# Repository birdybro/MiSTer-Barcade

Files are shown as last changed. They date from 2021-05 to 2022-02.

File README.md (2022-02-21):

# MiSTer-Barcade (WORK IN PROGRESS)

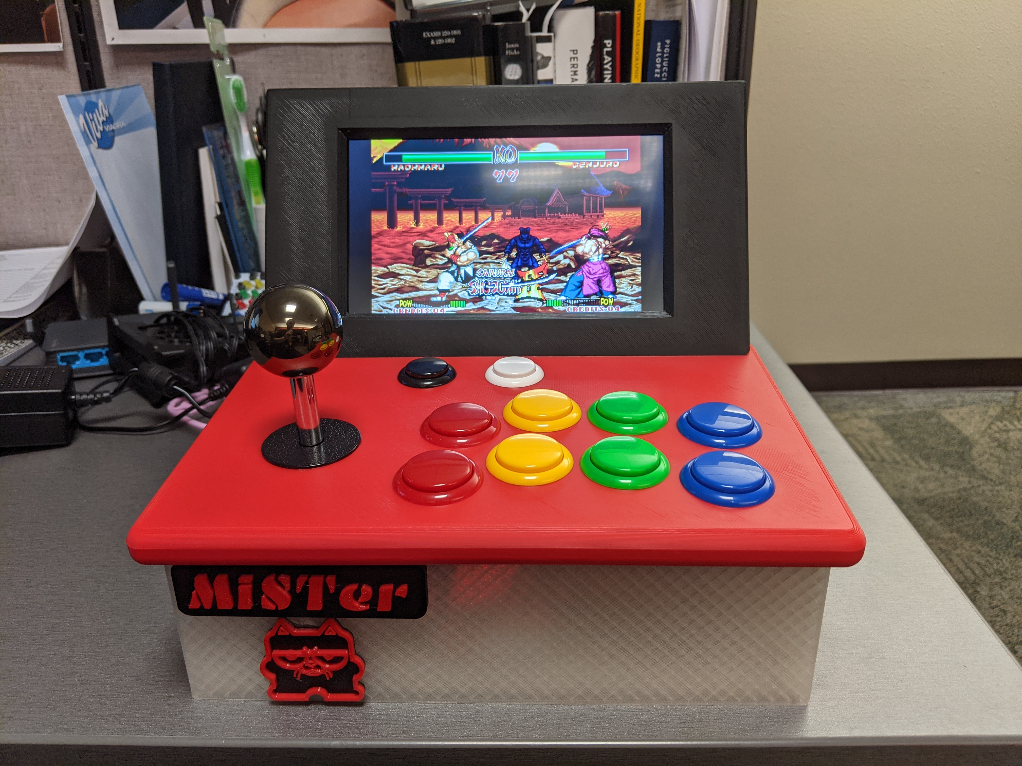
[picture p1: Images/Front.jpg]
Front of MiSTer Barcade


License: Creative Common Attributions License (and all thingiverse files were the same)

## Description

This is a project to build a Mini Bartop Arcade system with a MiSTer FPGA device integrated into it. It's not meant to be the best, it's just meant to be printable on cheap enthusiast 3d printers, using decently high quality components. This is not a very cheap project, if you want to make it cheaper, substitute a raspberry pi like the above-linked original source of the print from Thingiverse by iClint, and substitue the screen for a cheaper one from Aliexpress. All costs below are based on my personal selection of items as of May 2021. Your results and methods may vary.

## Tools Required
* [Metric Hex Wrench set](https://www.amazon.com/TEKTON-Wrench-Metric-13-Piece-25272/dp/B00I5THFR4/)
* [Loctite Ultra Gel Control Super Glue](https://www.amazon.com/dp/B01EZTPXEO) (or another cyanoacrylate super glue for bonding PLA pieces of different colors together)
* [Power drill](https://www.amazon.com/Dewalt-DCD771C2-Cordless-Lithium-Ion-Compact/dp/B00ET5VMTU/)
* [M3 Tap bits](https://www.amazon.com/Hakkin-Nitriding-Plastic-Tapping-Cutting/dp/B07S5KKCS4)

## Bill of Materials

### MiSTer FPGA Platform devices
* [Terasic DE10-Nano](https://www.digikey.com/en/products/detail/terasic-inc/P0496/6817231) - $170.00
* [Mean Well 5v 20W 4A Power Supply](https://www.digikey.com/en/products/detail/mean-well-usa-inc/GST25A05-P1J/7703645) - $16.63
* [Mean Well NEMA5-15P to IEC320 Power Cored](https://www.digikey.com/en/products/detail/mean-well-usa-inc/YP12-YC12/7707223) - $ 5.78
* [128MB MiSTer FPGA SDRAM Add-on Board](https://misteraddons.com/products/sdram-xsd-2-5-128mb) - $60.00
* [USB Hub Add-on board With DC Splitter and USB Bracket](https://misteraddons.com/products/usb-hub-v2-1) - $50.00
* [Heatsink](https://www.amazon.com/gp/product/B01JB8MQ76/) - $9.97
* [2 pin 5v 40mm Fan](https://www.amazon.com/GeeekPi-Raspberry-40x40x10mm-Brushless-Radiator/dp/B07X6CXQLN) - $7.99

### Sanwa Joystick and Buttons
* [Sanwa JLF-TP-8YT Joystick](https://focusattack.com/sanwa-jlf-tp-8yt-joystick/) - Add 5-Pin Double End Female Harness, GT-Y Octo Gate, and KOWAL Flat Plate Converter - $35.20
* [10x Japanese Style .110" Harness](https://focusattack.com/spare-japanese-style-110-harness-for-zero-delay-usb-encoder-pcb/) - $4.50
* [8x Sanwa OBSF 30MM Pushbuttons](https://focusattack.com/buttons/sanwa/30mm/obsf-30-pushbutton/) - $19.60
* [2x Sanwa OBSF 24MM Pushbuttons](https://focusattack.com/buttons/sanwa/24mm/obsf-24-pushbutton/) - $4.50
* [Daemonbite KTRL Arcade Mini controller encoder](https://www.daemonbite.com/product/ktrl-arcade-mini/) - $23.18

### Adafruit Components
* [HDMI 7" 800x480 Display Backpack - Without Touch](https://www.adafruit.com/product/2406) - $79.95
* [Stereo 3.7W Class D Audio Amplifier - MAX98306](https://www.adafruit.com/product/987) - $8.95
* [Speaker - 3" Diameter - 4 Ohm 3 Watt](https://www.adafruit.com/product/1314) - $1.95

### Screws/mounts and other hardware
* [8x (100 in pack) M3 Hex Nuts](https://www.amazon.com/gp/product/B01IWUSDYY/) - $5.22
* [30x (50 in pack) M3x12mm Countersunk Hex Bolt](https://www.amazon.com/gp/product/B01E6EIC2S/) - $6.99
* [12x (80 in pack) M3x4mm Machine Screws](https://www.amazon.com/gp/product/B07WCT6VY6/) - $6.99

### Estimated total cost
$

## 3D Printing

All 3d Printed Parts were sliced in PrusaSlicer on a Prusa i3 MK3S+ set to 0.30mm draft profile (15% grid infill) using Hatchbox PLA, unless otherwise stated below.

### Arcade Cabinet

* [Front Panel](https://cdn.thingiverse.com/assets/3f/01/7c/28/23/Front_Panel.stl)
* [Top Panel](https://cdn.thingiverse.com/assets/83/88/73/ff/92/Top_panel.stl)
* [Left Panel](https://cdn.thingiverse.com/assets/d0/cb/0b/19/be/left_Panel.stl)
* [Right Panel](https://cdn.thingiverse.com/assets/4f/1d/11/f3/97/right_panel.stl)
* [Back Panel](https://cdn.thingiverse.com/assets/98/93/cd/c9/cd/Back_Panel.stl) - Print with generated supports, 0.2 detachable. The handle area will slouch otherwise. You may have to paint on support blockers to keep unnecessary supports from being made around the edges which would cause it to exceed the build plate size.
* [Base Panel](https://cdn.thingiverse.com/assets/87/da/83/f2/4b/Base_panel.stl)
* [Rubber Feet](https://cdn.thingiverse.com/assets/22/47/79/eb/ac/Rubber_foot.stl) - Use TPU instead of PLA because "rubber".
* [Control Panel 10 Buttons Remix by alecreator](https://cdn.thingiverse.com/assets/d9/a1/a0/62/c1/Mini_Arcade_10_buttons.stl) - Used 0.20mm Quality profile instead because it is an obvious cosmetic surface. Use supports or else some loose bridging occurs on the interior wall that connects to the Bezel. You may have to use paint-on support blockers around the edges except for the bezel-facing interior wall in order for the slicer to fit it to your build plate.
* [Bezel for Adafruit 7" screen](https://cdn.thingiverse.com/assets/7f/f2/e9/ba/73/Bezel-Adafruit_7_Touchscreen.stl)

### Decorations

## Notes
* Power stereo amp from GPIO on the DE10-nano. 5v is required. Occupy pin 11 (5v) and 12 (GND) of the available header.
* Power the fan from GPIO on the DE10-nano. 3.3v is required. Occupy pin 29 (3.3v) and 30 (GND) of the available header.
* The video mode that needs to be placed into the MiSTer.ini file for the Adafruit 7" 800x480 non-touch display is `video_mode=800,70,48,10,480,13,3,29,34483`

## Credits

Original source of print here --> [Mini Arcade Machine by iClint](https://www.thingiverse.com/thing:2216740)

Remixed content from here --> [Bezel File from Mini Arcade Machine by Franks3dShop](https://www.thingiverse.com/thing:3529914) and here --> [10 button control panel for Mini Arcade Machine by alecreator](https://www.thingiverse.com/thing:3817837)

Pacman files from here --> [Glowing Pac Man & Phantom by FablabMoebius](https://www.thingiverse.com/thing:303447)

Electrical Hazard sign from here --> [Hazard Signs Cut Remix](https://www.thingiverse.com/thing:4870304)

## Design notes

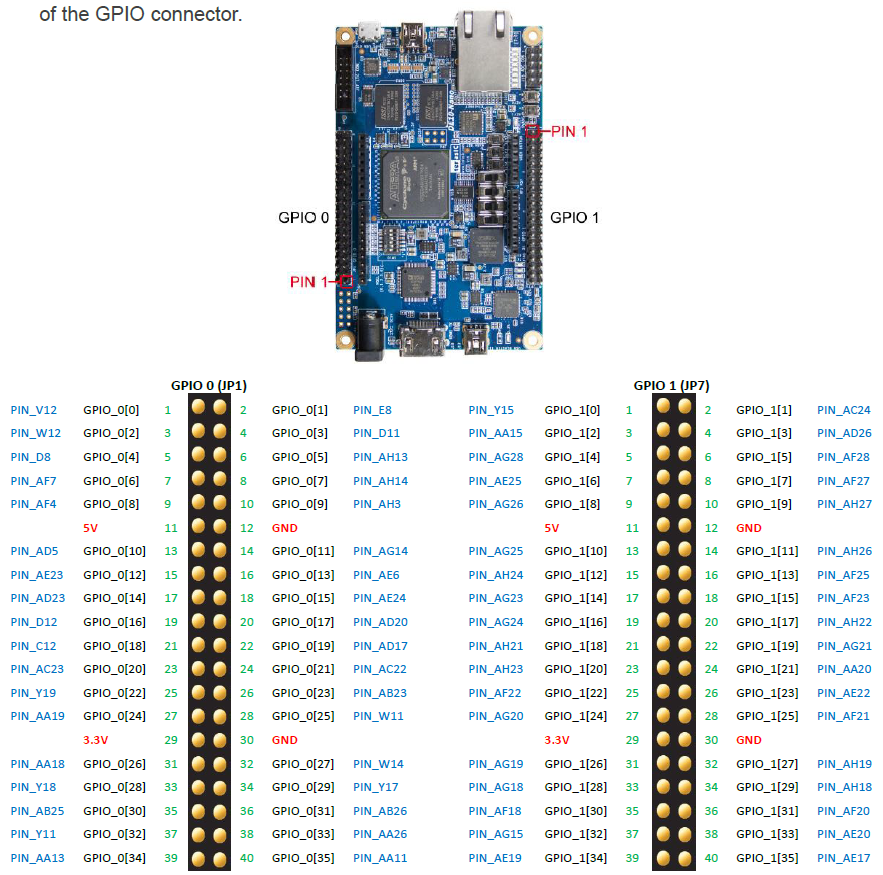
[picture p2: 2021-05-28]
Images/de10-nano_headers.png

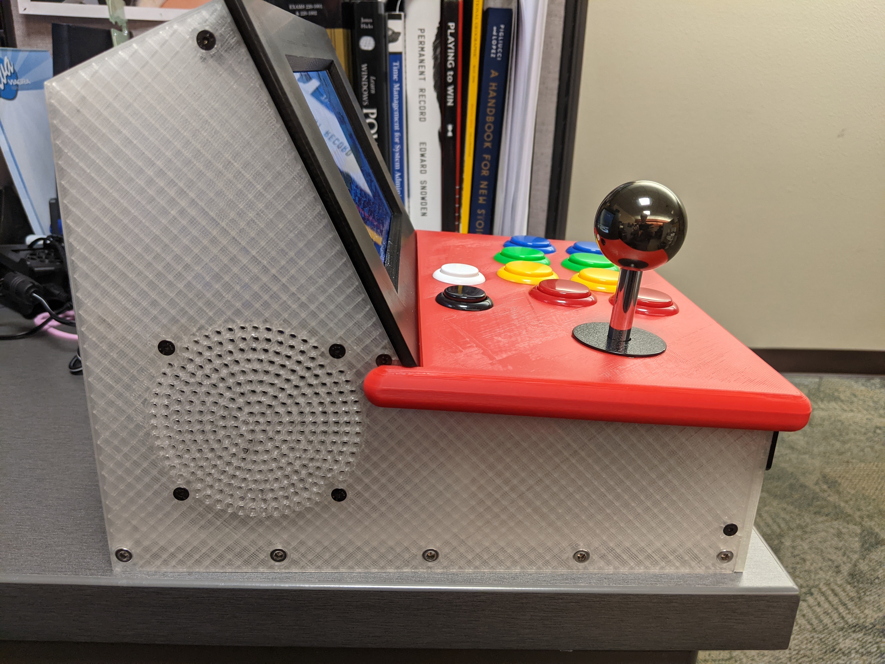
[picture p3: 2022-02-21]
Images/Side.jpg

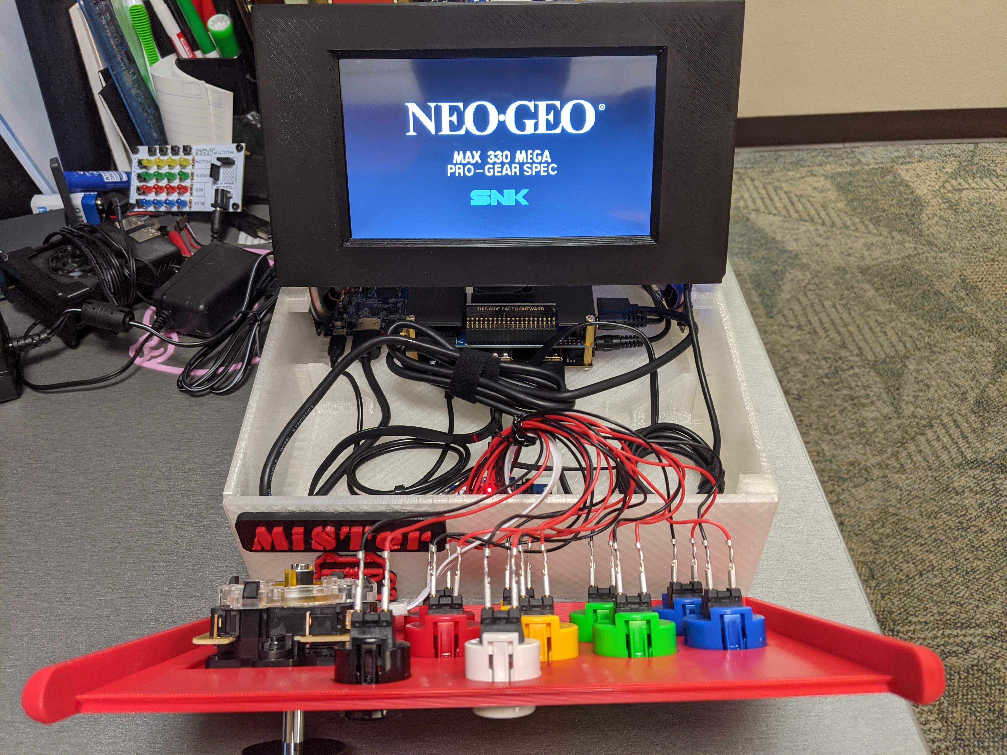
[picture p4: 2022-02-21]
Images/Inside.jpg

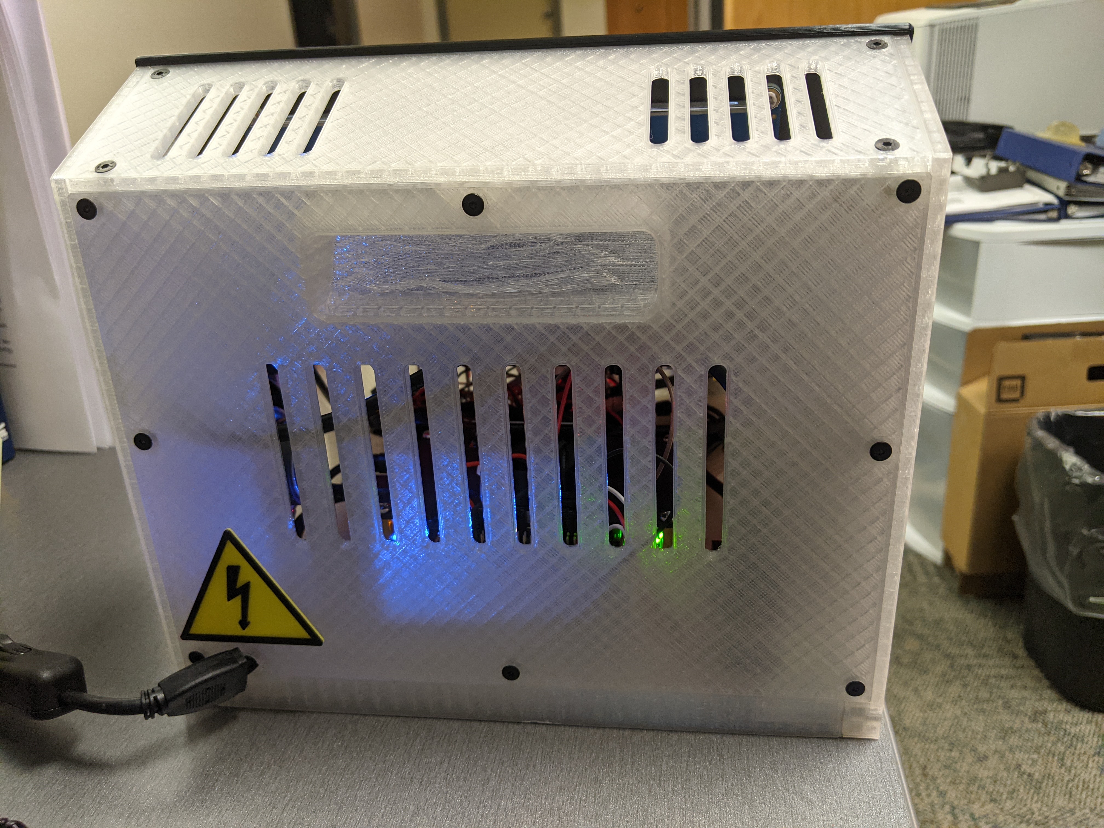
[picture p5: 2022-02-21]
Images/Rear.jpg

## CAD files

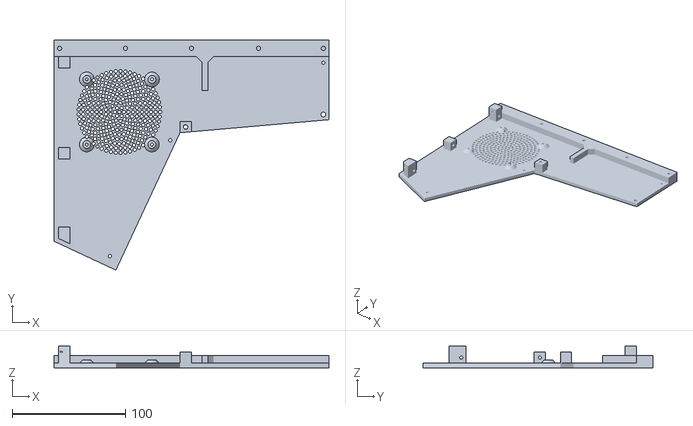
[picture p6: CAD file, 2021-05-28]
3d Printed Parts/Arcade Cabinet/left_Panel.stl
242.7 x 203.2 x 19.0

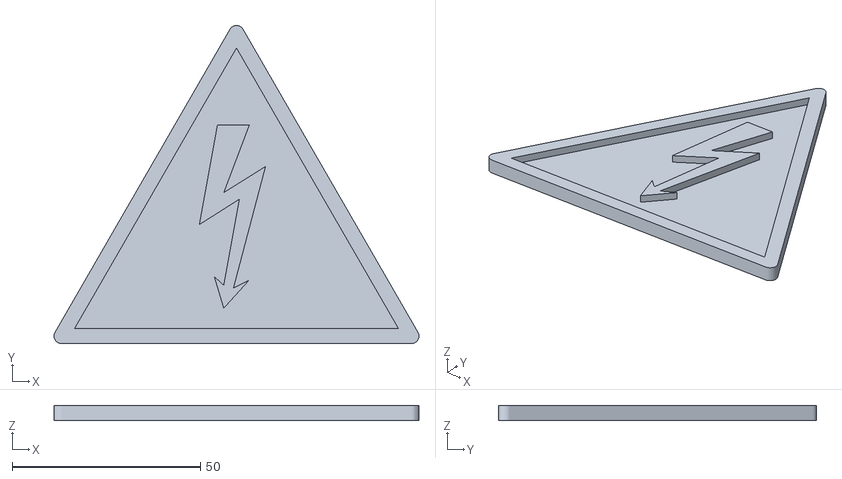
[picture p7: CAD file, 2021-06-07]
3d Printed Parts/Decorations/Back Panel/Electric_shock_-_High_voltage.stl
97.1 x 84.6 x 4.00

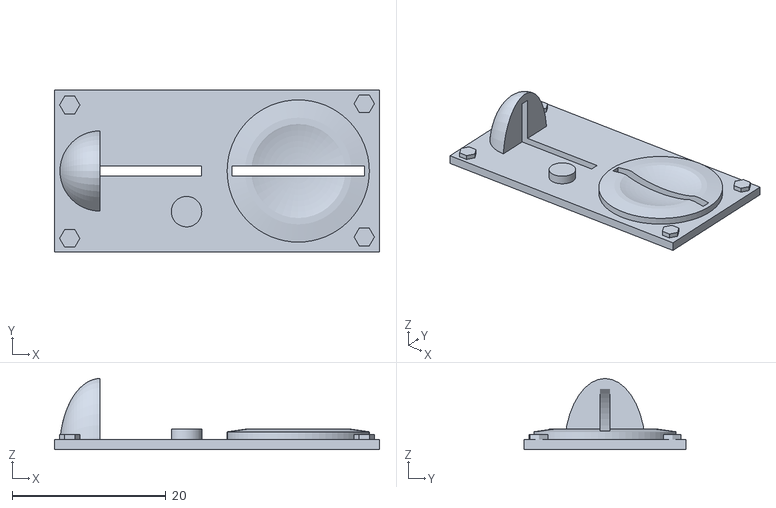
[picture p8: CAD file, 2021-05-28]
3d Printed Parts/Decorations/Front Panel/Coin_Slot.stl
42.2 x 21.1 x 9.24

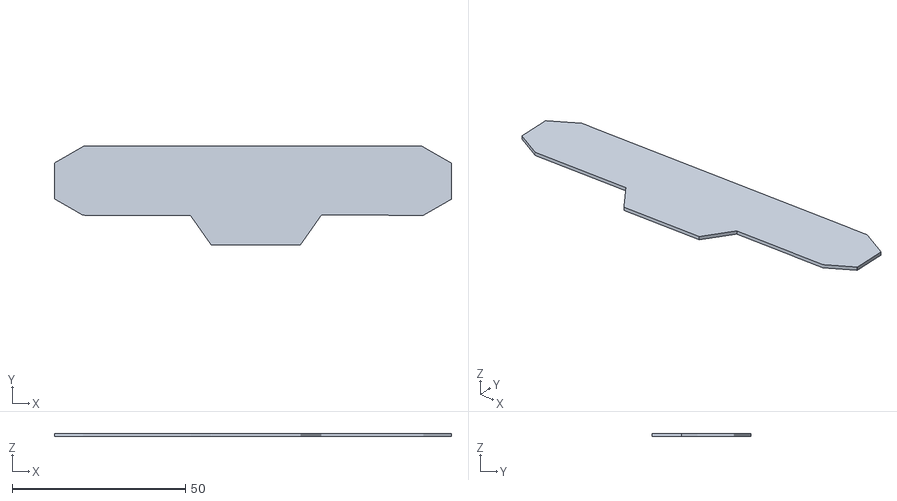
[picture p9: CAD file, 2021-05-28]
3d Printed Parts/Decorations/Other/Mister_Genesis_Logo_Base.stl
114.5 x 28.6 x 0.999

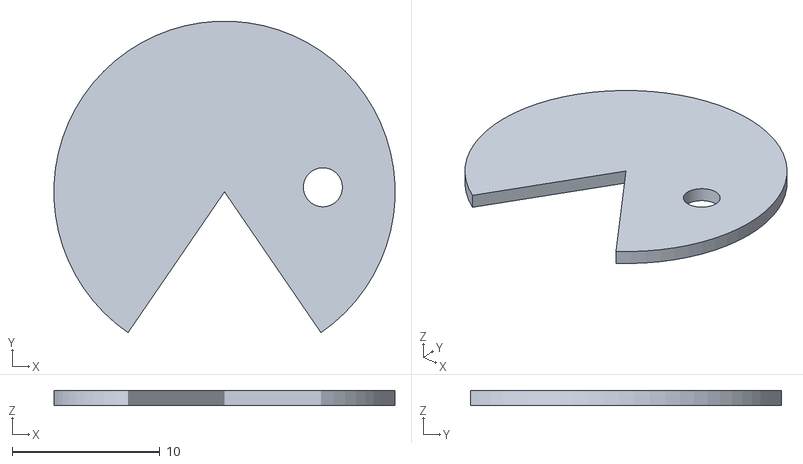
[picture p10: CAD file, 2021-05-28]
3d Printed Parts/Decorations/Other/Pacman.stl
23.1 x 21.1 x 0.99

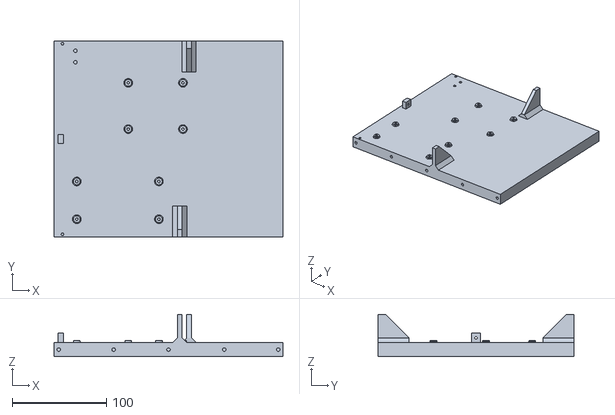
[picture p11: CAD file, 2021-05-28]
3d Printed Parts/Arcade Cabinet/Base_panel.stl
242.7 x 208.0 x 44.9

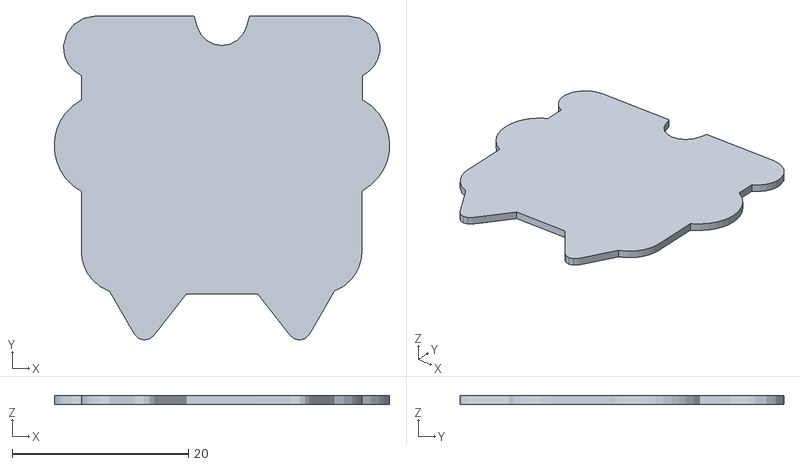
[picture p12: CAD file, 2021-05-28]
3d Printed Parts/Decorations/Other/mister_kun_emblem_base.stl
38.1 x 36.8 x 1.00

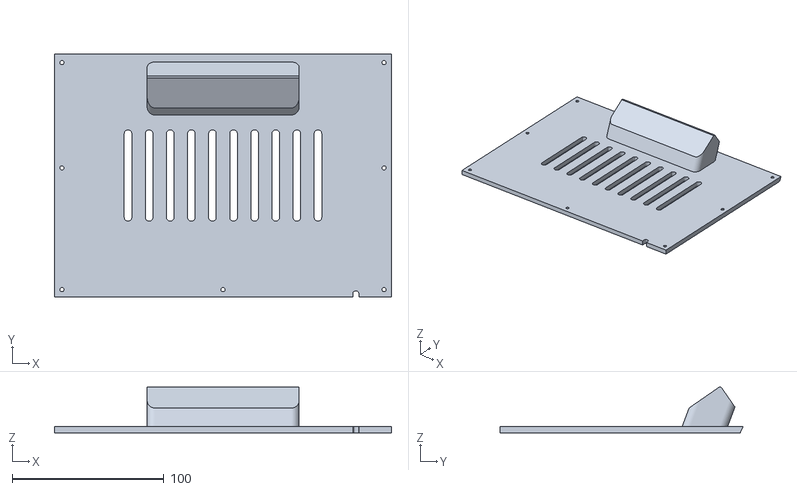
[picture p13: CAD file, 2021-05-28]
3d Printed Parts/Arcade Cabinet/Back_Panel.stl
221.8 x 160.0 x 30.0

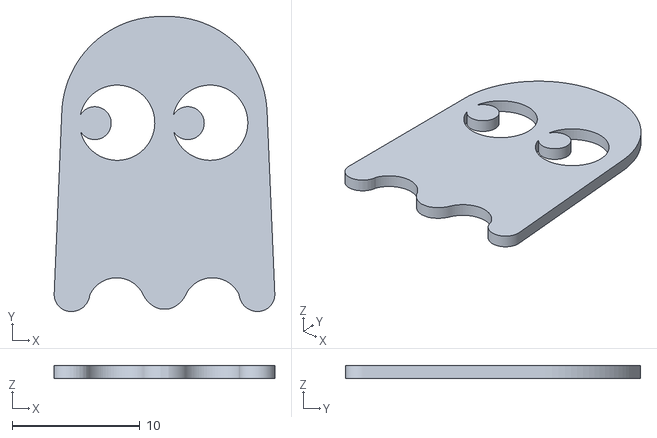
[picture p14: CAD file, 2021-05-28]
3d Printed Parts/Decorations/Other/Pacman_ghost.stl
17.2 x 23.1 x 0.99

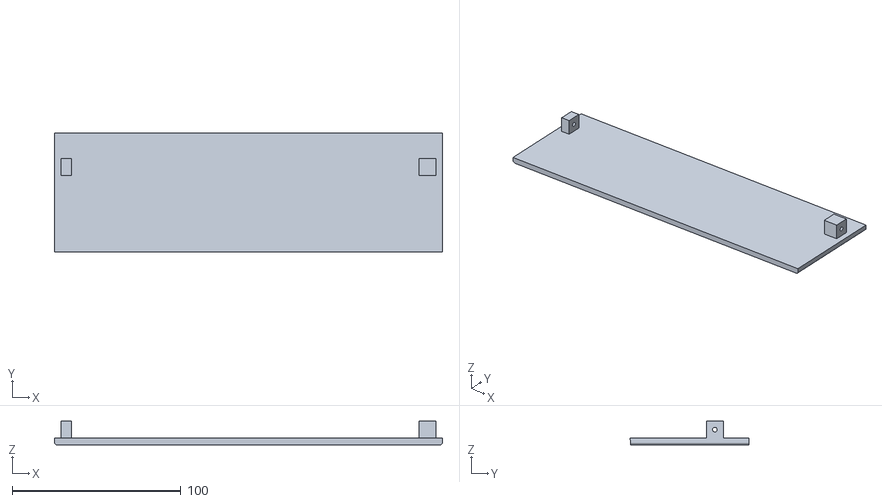
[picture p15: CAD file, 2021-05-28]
3d Printed Parts/Arcade Cabinet/Front_Panel.stl
230.0 x 70.4 x 14.0

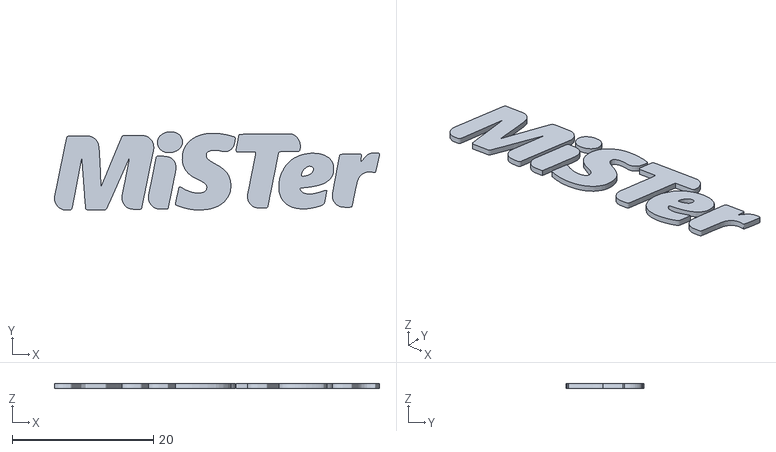
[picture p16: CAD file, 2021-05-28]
3d Printed Parts/Decorations/Other/MiSTer_Logo.stl
46.0 x 11.1 x 0.74

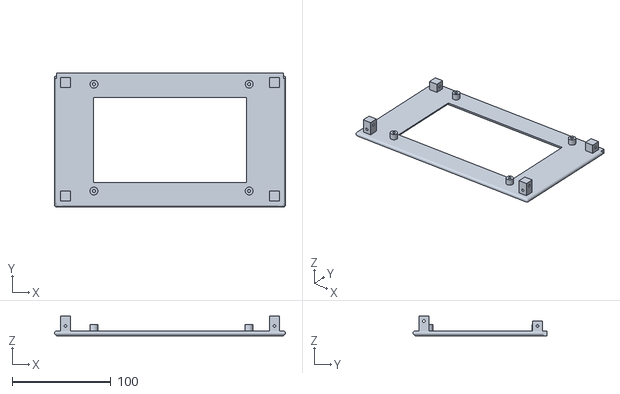
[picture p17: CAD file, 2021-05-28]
3d Printed Parts/Arcade Cabinet/Bezel-Adafruit_7_Touchscreen.stl
234.0 x 135.6 x 20.0

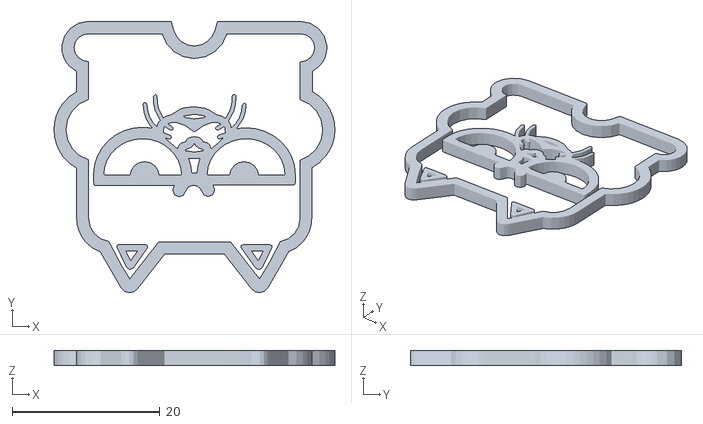
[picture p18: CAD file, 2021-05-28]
3d Printed Parts/Decorations/Other/mister_kun_emblem_outline.stl
38.1 x 36.8 x 2.00

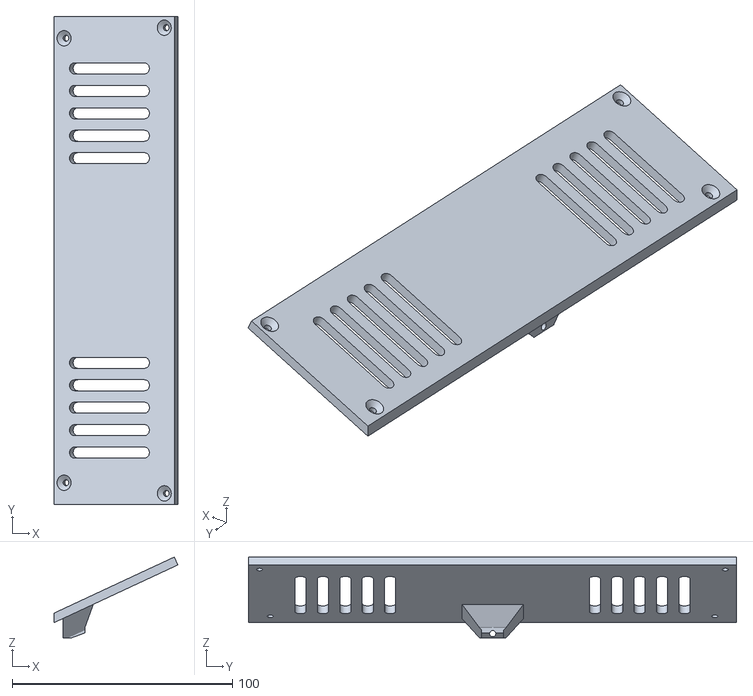
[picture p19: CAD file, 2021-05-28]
3d Printed Parts/Arcade Cabinet/Top_panel.stl
56.3 x 221.8 x 36.8

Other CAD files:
3d Printed Parts/Arcade Cabinet/right_panel.stl
3d Printed Parts/Decorations/Other/Pacman_Plate.stl
3d Printed Parts/Arcade Cabinet/Mini_Arcade_10_buttons.stl
3d Printed Parts/Decorations/Other/Pacman_dot.stl
3d Printed Parts/Arcade Cabinet/Rubber_foot.stl
3d Printed Parts/Decorations/Other/Mister_Genesis_Logo_Text.stl
3d Printed Parts/Other/mister_bolted_40mm_fan_plate.stl

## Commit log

2021-05-28 upload CAD and de10-nano headers image
    [Back_Panel.stl, Base_panel.stl, Bezel-Adafruit_7_Touchscreen.stl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]
2021-05-28 reorganize files and update readme
    [Pacman.stl, Pacman_Plate.stl, Pacman_dot.stl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]
2021-06-07 add daemonbite and change voltage cosmetic sign
    [Electric_shock_-_High_voltage.stl, Hazard_Base.stl, Hazard_Electric_Shock.stl]
